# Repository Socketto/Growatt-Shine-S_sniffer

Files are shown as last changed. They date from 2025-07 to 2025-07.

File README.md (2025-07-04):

# Growatt SPH Inverter Communication Sniffer

## Project Overview

This project aims to develop a custom hardware interface and software system for reading and interpreting communication data from a **Growatt SPH series inverter**. The system intercepts the communication between the inverter and the official **ShineWiFi-S dongle**, using signal conversion and a **Raspberry Pi** to capture and decode the **Modbus RTU protocol** used by Growatt.
  
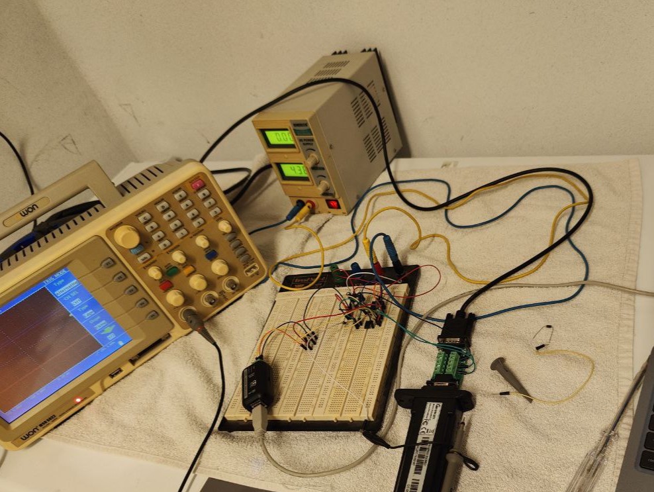
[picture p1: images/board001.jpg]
Board1
 
   
## System Architecture

The solution is composed of the following main stages:

1. **Sniffing the RS-232 Communication**  
   The inverter and ShineWiFi-S dongle communicate over an **RS-232 serial connection**. This project taps into that communication without interfering with the normal operation of either device.

2. **RS-232 to TTL Conversion**  
   Because RS-232 voltage levels are not directly compatible with most microcontrollers or logic analyzers, the tapped signal is first converted to **TTL level signals** using an RS-232 to TTL converter module (MAX232).

3. **TTL to RS-485 Conversion**  
   To ensure signal integrity over longer distances and allow for differential signaling, the TTL signal is then converted to **RS-485** using a TTL to RS-485 transceiver (MAX485).

4. **Data Acquisition via Raspberry Pi**  
   The RS-485 output is connected to a **Raspberry Pi**, which acts as the main controller. The Raspberry Pi receives the data through its serial interface.

5. **Modbus Decoding and Data Interpretation**  
   A **Python script** running on the Raspberry Pi listens to the serial port, decodes the Modbus RTU frames, and extracts relevant data such as:

   - Inverter status
   - Power production
   - Battery charge/discharge
   - Grid voltage and frequency
   - And other available telemetry

## Hardware Components

- Growatt SPH series inverter
- ShineWiFi-S dongle (OEM)
- Breakout DB9
- Raspberry Pi (any model with UART support)
- Optional: Logic level shifters and protective diodes

## Key Advantages

- **Non-intrusive monitoring** of Growatt inverter communication
- **Real-time access** to detailed inverter data
- Enables custom logging, alerting, or integration with home automation platforms (e.g., Home Assistant)

## Disclaimer

This project involves tapping into proprietary communication and working with high voltages indirectly. **Ensure all safety precautions are followed** and use this project at your own risk. This is intended for **educational and personal use only**.

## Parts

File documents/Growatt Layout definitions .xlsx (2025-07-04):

Instruction：Register range for various types of inverter TL-X（MIN Type）：03 register range：0~124,3000~3124；04 register range：3000~3124,3125~3249 TL3-X(MAX、MID、MAC Type)：03 register range：0~124,125~249； 04 register range：0~124,125~249 Storage(MIX Type)：03 register range：0~124,1000~1124；04 register range：0~124,1000~1124 Storage(SPA Type)：03 register range：0~124,1000~1124；04 register range：1000~1124,2000~2124 Storage(SPH Type)：03 register range：0~124,1000~1124；04 register range：0~124,1000~1124
4.2 Input Reg
NO. | Variable Name | Description | Value | Unit | Note | Grott Field name | Grott Offset | Remark | Grott Layout definition
First group
0 | Inverter Status | Inverter run state | 0:waiting, 1:normal, 3:fault |  |  | pvstatus | 158 |  | "pvstatus" : {"value" :158, "length" : 2, "type" : "num"},
1 | Ppv H | Input power (high) |  | 0.1W |  | pvpowerin | 162 |  | "pvpowerin" : {"value" :162, "length" : 4, "type" : "num", "divide" : 10},
2 | Ppv L | Input power (low) |  | 0.1W |  |  | 166
3 | Vpv1 | PV1 voltage |  | 0.1V |  | pv1voltage | 170 |  | "pv1voltage" : {"value" :170, "length" : 2, "type" : "num", "divide" : 10},
4 | PV1Curr | PV1 input current |  | 0.1A |  | pv1current | 174 |  | "pv1current" : {"value" :174, "length" : 2, "type" : "num", "divide" : 10},
5 | Ppv1 H | PV1 input power(high) |  | 0.1W |  | pv1watt | 178 |  | "pv1watt" : {"value" :178, "length" : 4, "type" : "num", "divide" : 10},
6 | Ppv1 L | PV1 input power(low) |  | 0.1W |  |  | 182
7 | Vpv2 | PV2 voltage |  | 0.1V |  | pv2voltage | 186 |  | "pv2voltage" : {"value" :186, "length" : 2, "type" : "num", "divide" : 10},
8 | PV2Curr | PV2 input current |  | 0.1A |  | pv2current | 190 |  | "pv2current" : {"value" :190, "length" : 2, "type" : "num", "divide" : 10},
9 | Ppv2 H | PV2 input power (high) |  | 0.1W |  | pv2watt | 194 |  | "pv2watt" : {"value" :194, "length" : 4, "type" : "num", "divide" : 10},
10 | Ppv2 L | PV2 input power (low) |  | 0.1W |  |  | 198
11 | Vpv3 | PV3 voltage |  | 0.1V |  |  | 202
12 | PV3Curr | PV3 input current |  | 0.1A |  |  | 206
13 | Ppv3 H | PV3 input power (high) |  | 0.1W |  |  | 210
14 | Ppv3 L | PV3 input power (low) |  | 0.1W |  |  | 214
15 | Vpv4 | PV4 voltage |  | 0.1V |  |  | 218
16 | PV4Curr | PV4 input current |  | 0.1A |  |  | 222
17 | Ppv4 H | PV4 input power (high) |  | 0.1W |  |  | 226
18 | Ppv4 L | PV4 input power (low) |  | 0.1W |  |  | 230
19 | Vpv5 | PV5 voltage |  | 0.1V |  |  | 234
20 | PV5Curr | PV5 input current |  | 0.1A |  |  | 238
21 | Ppv5H | PV5 input power(high) |  | 0.1W |  |  | 242
22 | Ppv5 L | PV5 input power(low) |  | 0.1W |  |  | 246
23 | Vpv6 | PV6 voltage |  | 0.1V |  |  | 250
24 | PV6Curr | PV6 input current |  | 0.1A |  |  | 254
25 | Ppv6 H | PV6 input power (high) |  | 0.1W |  |  | 258
26 | Ppv6 L | PV6 input power (low) |  | 0.1W |  |  | 262
27 | Vpv7 | PV7 voltage |  | 0.1V |  |  | 266
28 | PV7Curr | PV7 input current |  | 0.1A |  |  | 270
29 | Ppv7 H | PV7 input power (high) |  | 0.1W |  |  | 274
30 | Ppv7 L | PV7 input power (low) |  | 0.1W |  |  | 278
31 | Vpv8 | PV8 voltage |  | 0.1V |  |  | 282
32 | PV8Curr | PV8 input current |  | 0.1A |  |  | 286
33 | Ppv8 H | PV8 input power (high) |  | 0.1W |  |  | 290
34 | Ppv8 L | PV8 input power (low) |  | 0.1W |  |  | 294
35 | Pac H | Output power (high) |  | 0.1W |  | pvpowerout | 298 |  | "pvpowerout" : {"value" :298, "length" : 4, "type" : "numx", "divide" : 10},
36 | Pac L | Output power (low) |  | 0.1W |  |  | 302
37 | Fac | Grid frequency |  | 0.01Hz |  | pvfrequentie | 306 |  | "pvfrequentie" : {"value" :306, "length" : 2, "type" : "num", "divide" : 100},
38 | Vac1 | Three/single phase grid voltage |  | 0.1V |  | pvgridvoltage | 310 |  | "pvgridvoltage" : {"value" :310, "length" : 2, "type" : "num", "divide" : 10},
39 | Iac1 | Three/single phase grid output current |  | 0.1A |  | pvgridcurrent | 314 |  | "pvgridcurrent" : {"value" :314, "length" : 2, "type" : "num", "divide" : 10},
40 | Pac1 H | Three/single phase grid output watt VA (high) |  | 0.1VA |  | pvgridpower | 318 |  | "pvgridpower" : {"value" :318, "length" : 4, "type" : "num", "divide" : 10},
41 | Pac1 L | Three/single phase grid output watt VA(low) |  | 0.1VA |  |  | 322
42 | Vac2 | Three phase grid voltage |  | 0.1V |  | pvgridvoltage2 | 326 |  | "pvgridvoltage2" : {"value" :326, "length" : 2, "type" : "num", "divide" : 10},
43 | Iac2 | Three phase grid output current |  | 0.1A |  | pvgridcurrent2 | 330 |  | "pvgridcurrent2" : {"value" :330, "length" : 2, "type" : "num", "divide" : 10},
44 | Pac2 H | Three phase grid output power (high) |  | 0.1VA |  | pvgridpower2 | 334 |  | "pvgridpower2" : {"value" :334, "length" : 4, "type" : "num", "divide" : 10},
45 | Pac2 L | Three phase grid output power (low) |  | 0.1VA |  | pvgridvoltage3 | 338
46 | Vac3 | Three phase grid voltage |  | 0.1V |  |  | 342 |  | "pvgridvoltage3" : {"value" :342, "length" : 2, "type" : "num", "divide" : 10},
47 | Iac3 | Three phase grid output current |  | 0.1A |  | pvgridcurrent | 346 |  | "pvgridcurrent3" : {"value" :346, "length" : 2, "type" : "num", "divide" : 10},
48 | Pac3 H | Three phase grid output power (high) |  | 0.1VA |  | pvgridpower | 350 |  | "pvgridpower3" : {"value" :350, "length" : 4, "type" : "num", "divide" : 10},
49 | Pac3 L | Three phase grid output power (low) |  | 0.1VA |  |  | 354
50 | Vac_RS | Three phase grid voltage |  | 0.1V | Line voltage |  | 358
51 | Vac_ST | Three phase grid voltage |  | 0.1V | Line voltage |  | 362
52 | Vac_TR | Three phase grid voltage |  | 0.1V | Line voltage |  | 366
53 | Eactoday H | Today generate energy (high) |  | 0.1kWH |  | eactoday. Pvenergytoday | 370 |  | "eactoday" : {"value" :370, "length" : 4, "type" : "num", "divide" : 10}, "pvenergytoday" : {"value" :370, "length" : 4, "type" : "num", "divide" : 10},
54 | Eac today L | Today generate energy (low) |  | 0.1kWH |  |  | 374
55 | Eac total H | Total generate energy (high) |  | 0.1kWH |  | eactotal | 378 |  | "eactotal" : {"value" :378, "length" : 4, "type" : "num", "divide" : 10},
56 | Eac total L | Total generate energy (low) |  | 0.1kWH |  |  | 382
57 | Time total H | Work time total (high) |  | 0.5s |  | totworktime | 386 |  | "totworktime" : {"value" :386, "length" : 4, "type" : "num", "divide" : 7200},
58 | Time total L | Work time total (low) |  | 0.5s |  |  | 390
59 | Epv1_today H | PV1Energy today(high) |  | 0.1kWh |  | epv1today | 394 |  | "epv1today" : {"value" :394, "length" : 4, "type" : "num", "divide" : 10},
60 | Epv1_today L | PV1Energy today (low) |  | 0.1kWh |  |  | 398
61 | Epv1_total H | PV1Energy total(high) |  | 0.1kWh |  | epv1total | 402 |  | "epv1total" : {"value" :402, "length" : 4, "type" : "num", "divide" : 10},
62 | Epv1_total L | PV1Energy total (low) |  | 0.1kWh |  |  | 406
63 | Epv2_today H | PV2Energy today(high) |  | 0.1kWh |  | epv2today | 410 |  | "epv2today" : {"value" :410, "length" : 4, "type" : "num", "divide" : 10},
64 | Epv2_today L | PV2Energy today (low) |  | 0.1kWh |  |  | 414
65 | Epv2_total H | PV2Energy total(high) |  | 0.1kWh |  | epv2total | 418 |  | "epv2total" : {"value" :418, "length" : 4, "type" : "num", "divide" : 10},
66 | Epv2_total L | PV2Energy total (low) |  | 0.1kWh |  |  | 422
67 | Epv3_today H | PV3 Energy today(high) |  | 0.1kWh |  |  | 426
68 | Epv3_today L | PV3 Energy today (low) |  | 0.1kWh |  |  | 430
69 | Epv3_total H | PV3 Energy total(high) |  | 0.1kWh |  |  | 434
70 | Epv3_total L | PV3 Energy total (low) |  | 0.1kWh |  |  | 438
71 | Epv4_today H | PV4Energy today(high) |  | 0.1kWh |  |  | 442
72 | Epv4_today L | PV4Energy today (low) |  | 0.1kWh |  |  | 446
73 | Epv4_total H | PV4Energy total(high) |  | 0.1kWh |  |  | 450
74 | Epv4_total L | PV4Energy total (low) |  | 0.1kWh |  |  | 454
75 | Epv5_today H | PV5Energy today(high) |  | 0.1kWh |  |  | 458
76 | Epv5_today L | PV5Energy today (low) |  | 0.1kWh |  |  | 462
77 | Epv5_total H | PV5Energy total(high) |  | 0.1kWh |  |  | 466
78 | Epv5_total L | PV5Energy total (low) |  | 0.1kWh |  |  | 470
79 | Epv6_today H | PV6Energy today(high) |  | 0.1kWh |  |  | 474
80 | Epv6_today L | PV6Energy today (low) |  | 0.1kWh |  |  | 478
81 | Epv6_total H | PV6Energy total(high) |  | 0.1kWh |  |  | 482
82 | Epv6_total L | PV6Energy total (low) |  | 0.1kWh |  |  | 486
83 | Epv7_today H | PV7Energy today(high) |  | 0.1kWh |  |  | 490
84 | Epv7_today L | PV7Energy today (low) |  | 0.1kWh |  |  | 494
85 | Epv7_total H | PV7 Energy total(high) |  | 0.1kWh |  |  | 498
86 | Epv7_total L | PV7Energy total (low) |  | 0.1kWh |  |  | 502
87 | Epv8_today H | PV8Energy today(high) |  | 0.1kWh |  |  | 506
88 | Epv8_today L | PV8Energy today (low) |  | 0.1kWh |  |  | 510
89 | Epv8_total H | PV8Energy total(high) |  | 0.1kWh |  |  | 514
90 | Epv8_total L | PV8Energy total (low) |  | 0.1kWh |  |  | 518
91 | Epv_total H | PV Energy total(high) |  | 0.1kWh |  | epvtotal | 522 |  | "epvtotal" : {"value" :522, "length" : 4, "type" : "num", "divide" : 10},
92 | Epv_total L | PV Energy total (low) |  | 0.1kWh |  |  | 526
93 | Temp1 | Inverter temperature |  | 0.1C |  | pvtemperature | 530 |  | "pvtemperature" : {"value" :530, "length" : 2, "type" : "num", "divide" : 10},
94 | Temp2 | The inside IPM in inverter Temperature |  | 0.1C |  | pvipmtemperature" | 534 |  | "pvipmtemperature" : {"value" :534, "length" : 2, "type" : "num", "divide" : 10},
95 | Temp3 | Boost temperature |  | 0.1C |  | pvboosttemp | 538 |  | "pvboosttemp" : {"value" :538, "length" : 2, "type" : "num", "divide" : 10},
96 | Temp4 |  |  |  | reserved |  | 542
97 | uwBatVolt_DSP | BatVolt_DSP |  | 0.1V | BatVolt(DSP) | bat_dsp | 546 | Only shown with includeall = True (.ini) or gincludeall ="True" (docker) | "bat_dsp" : {"value" :546, "length" : 2, "type" : "num", "divide" : 10},
98 | P Bus Voltage | P Bus inside Voltage |  | 0.1V |  | pbusvolt | 550 | Only shown with includeall = True (.ini) or gincludeall ="True" (docker) | "pbusvolt" : {"value" :550, "length" : 2, "type" : "num", "divide" : 10,"incl" : "no"},
99 | N Bus Voltage | N Bus inside Voltage |  | 0.1V |  | #nbusvolt | 554 | Only shown with includeall = True (.ini) or gincludeall ="True" (docker) | "#nbusvolt" : {"value" :554, "length" : 2, "type" : "num", "divide" : 10,"incl" : "no"},
100 | IPF | Inverter output PF now | 0-20000 |  |  | #ipf | 558 | Only shown with includeall = True (.ini) or gincludeall ="True" (docker) | "#ipf" : {"value" :558, "length" : 2, "type" : "num", "divide" : 10,"incl" : "no"},
101 | RealOPPercent | Real Output power Percent |  | 1% |  | #realoppercent | 562 | Only shown with includeall = True (.ini) or gincludeall ="True" (docker) | "#realoppercent" : {"value" :562, "length" : 2, "type" : "num", "divide" : 100,"incl" : "no"},
102 | OPFullwatt H | Output Maxpower Limited high |  |  |  | #opfullwat | 566 | Only shown with includeall = True (.ini) or gincludeall ="True" (docker) | "#opfullwatt" : {"value" :566, "length" : 4, "type" : "num", "divide" : 10,"incl" : "no"},
103 | OPFullwatt L | Output Maxpower Limited low |  | 0.1W |  |  | 570
104 | DeratingMode | DeratingMode | 0:no derate; 1:PV; 2:*; 3:Vac; 4:Fac; 5:Tboost; 6:Tinv; 7:Control; 8:*; 9:*OverBack ByTime; |  |  | #deratingmode | 574 | Only shown with includeall = True (.ini) or gincludeall ="True" (docker) | "#deratingmode" : {"value" :574, "length" : 2, "type" : "num", "divide" : 1,"incl" : "no"},
105 | Fault code | Inverter fault code | &*1 |  | MAX |  | 578
106 | Fault Bitcode H | Inverter fault code high | &*8 |  | MAX |  | 582
107 | Fault Bitcode L | Inverter fault code low |  |  |  |  | 586
108 | RemoteCtrlEn | / | 0.Load First 1.BatFirst 2.Grid | / | StoragePow er (SPA) |  | 590
109 | RemoteCtrlPow er | / |  | / | StoragePow er (SPA) |  | 594
110 | Warning bit H | Warning bit H | &*8 |  |  |  | 598
111 | Warning bit L | Warning bit L |  |  |  |  | 602
112 | bINVWarnCode | bINVWarnCode |  |  | MAX |  | 606 |  | "eacharge_today" : {"value" :606, "length" : 4, "type" : "num", "divide" : 10},
 | EACharge_Today _H | ACCharge energy today |  | 0.1kwh | Storage Power | acharge_today
113 | real Power Percent | real Power Percent | 0-100 | % | MAX |  | 610
 | EACharge_Today _L | ACCharge energy today |  | 0.1kwh | Storage Power
114 | inv start delay time | inv start delay time |  |  | MAX |  | 614 |  | "eacharge_total" : {"value" :614, "length" : 4, "type" : "num", "divide" : 10},
 | EACharge_Total _H | ACCharge energy total |  | 0.1kwh | Storage Power | eacharge_total
115 | bINVAllFaultCod e | bINVAllFaultCode |  |  | MAX |  | 618
 | EACharge_Total _L | ACCharge energy total |  | 0.1kwh | Storage Power |  | 158
116 | AC charge Power_H | Grid power to local load |  | 0.1kwh | Storage Power |  | 622
117 | AC charge Power_L | Grid power to local load |  | 0.1kwh | Storage Power |  | 626
118 | Priority | 0:Load First 1:Battery First 2:Grid First |  |  | Storage Power |  | 630
119 | Battery Type | 0：Lead-acid 1：Lithium battery |  |  | Storage Power | batterytype | 634 |  | "batterytype" : {"value" :634, "length" : 2, "type" : "num", "divide" : 1},
120 | AutoProofreadC MD | Aging mode 自动校准命令 |  |  | Storage Power |  | 638
… | reserved |  |  |  | reserved
124 | reserved |  |  |  | reserved |  | 654
Second group
125 | PID PV1+ Voltage | PID PV1PE Volt | 0~1000V | 0.1V
126 | PID PV1+ Current | PID PV1PE Curr | -10~10mA | 0.1mA
127 | PID PV2+ Voltage | PID PV2PE Volt | 0~1000V | 0.1V
128 | PID PV2+ Current | PID PV2PE Curr | -10~10mA | 0.1mA
129 | PID PV3+ Voltage | PID PV3PE Volt | 0~1000V | 0.1V
130 | PID PV3+ Current | PID PV3PE Curr | -10~10mA | 0.1mA
131 | PID PV4+ Voltage | PID PV4PE Volt | 0~1000V | 0.1V
132 | PID PV4+ Current | PID PV4PE Curr | -10~10mA | 0.1mA
133 | PID PV5+ Voltage | PID PV5PE Volt | 0~1000V | 0.1V
134 | PID PV5+ Current | PID PV5PE Curr | -10~10mA | 0.1mA
135 | PID PV6+ Voltage | PID PV6PE Volt | 0~1000V | 0.1V
136 | PID PV6+ Current | PID PV6PE Curr | -10~10mA | 0.1mA
137 | PID PV7+ Voltage | PID PV7PE Volt | 0~1000V | 0.1V
138 | PID PV7+ Current | PID PV7PE Curr | -10~10mA | 0.1mA
139 | PID PV8+ Voltage | PID PV8PE Volt | 0~1000V | 0.1V
140 | PID PV8+ Current | PID PV8PE Curr | -10~10mA | 0.1mA
141 | PID Status | Bit0~7:PID Working Status 1:Wait Status 2:Normal Status 3:Fault Status Bit8~15:Reversed | 0~3
142 | V _String1 | PV String1 voltage |  | 0.1V
143 | Curr _String1 | PV String1 current | -15~15A | 0.1A
144 | V _String2 | PV String2 voltage |  | 0.1V
145 | Curr _String2 | PV String2 current | -15~15A | 0.1A
146 | V _String3 | PV String3 voltage |  | 0.1V
147 | Curr _String3 | PV String3 current | -15~15A | 0.1A
148 | V _String4 | PV String4 voltage |  | 0.1V
149 | Curr _String4 | PV String4 current | -15~15A | 0.1A
150 | V _String5 | PV String5 voltage |  | 0.1V
151 | Curr _String5 | PV String5 current | -15~15A | 0.1A
152 | V _String6 | PV String6 voltage |  | 0.1V
153 | Curr _String6 | PV String6 current | -15~15A | 0.1A
154 | V _String7 | PV String7 voltage |  | 0.1V
155 | Curr _String7 | PV String7 current | -15~15A | 0.1A
156 | V _String8 | PV String8 voltage |  | 0.1V
157 | Curr _String8 | PV String8 current | -15A~15A | 0.1A
158 | V _String9 | PV String9 voltage |  | 0.1V
159 | Curr _String9 | PV String9 current | -15A~15A | 0.1A
160 | V _String10 | PV String10 voltage |  | 0.1V
161 | Curr _String10 | PV String10 current | -15~15A | 0.1A
162 | V _String11 | PV String11 voltage |  | 0.1V
163 | Curr _String11 | PV String11 current | -15~15A | 0.1A
164 | V _String12 | PV String12 voltage |  | 0.1V
165 | Curr _String12 | PV String12 current | -15~15A | 0.1A
166 | V _String13 | PV String13 voltage |  | 0.1V
167 | Curr _String13 | PV String13 current | -15A~15A | 0.1A
168 | V _String14 | PV String14 voltage |  | 0.1V
169 | Curr _String14 | PV String14 current | -15~15A | 0.1A
170 | V _String15 | PV String15 voltage |  | 0.1V
171 | Curr _String15 | PV String15 current | -15~15A | 0.1A
172 | V _String16 | PV String16 voltage |  | 0.1V
173 | Curr _String16 | PV String16 current | -15~15A | 0.1A
174 | StrUnmatch | Bit0~15: String1~16 unmatch |  |  | suggestive
175 | StrCurrentUnblan ce | Bit0~15: String1~16 current unblance |  |  | suggestive
176 | StrDisconnect | Bit0~15: String1~16 disconnect |  |  | suggestive
177 | PIDFaultCode | Bit0:Output over voltage Bit1: ISO fault Bit2: BUS voltage abnormal Bit3~15:reserved
178 | String Prompt | String Prompt Bit0:String Unmatch Bit1:StrDisconnect Bit2:StrCurrentUnblance Bit3~15:reserved
179 | PV Warning Value | PV Warning Value
180 | DSP075 Warning Value | DSP075 Warning Value
181 | DSP075 Fault Value | DSP075 Fault Value
182 | DSP067 Debug Data1 | DSP067 Debug Data1
183 | DSP067 Debug Data2 | DSP067 Debug Data2
184 | DSP067 Debug Data3 | DSP067 Debug Data3
185 | DSP067 Debug Data4 | DSP067 Debug Data4
186 | DSP067 Debug Data5 | DSP067 Debug Data5
187 | DSP067 Debug Data6 | DSP067 Debug Data6
188 | DSP067 Debug Data7 | DSP067 Debug Data7
189 | DSP067 Debug Data8 | DSP067 Debug Data8
190 | DSP075 Debug Data1 | DSP075 Debug Data1
191 | DSP075 Debug Data2 | DSP075 Debug Data2
192 | DSP075 Debug Data3 | DSP075 Debug Data3
193 | DSP075 Debug Data4 | DSP075 Debug Data4
194 | DSP075 Debug Data55 | DSP075 Debug Data5
195 | DSP075 Debug Data6 | DSP075 Debug Data6
196 | DSP075 Debug Data7 | DSP075 Debug Data7
197 | DSP075 Debug Data8 | DSP075 Debug Data8
198 | bUSBAgingTestOk Flag | USBAgingTestOkFlag | 0-1
199 | bFlashEraseAging OkFlag | FlashEraseAgingOkFlag | 0-1
200 | PVISO | PVISOValue |  | KΩ
201 | R_DCI | R DCI Curr |  | 0.1mA
202 | S_DCI | S DCI Curr |  | 0.1mA
203 | T_DCI | T DCI Curr |  | 0.1mA
204 | PID_Bus | PIDBusVolt |  | 0.1V
205 | GFCI | GFCI Curr |  | mA
206 | SVG/APF Status+SVGAPFEq ualRatio | SVG/APF Status+SVGAPFEqualRatio | High 8 bit： SVGAPFEqua lRatio Low 8 bit： SVG/APF Status 0:None 1:SVG Run 2:APF Run 3:SVG/APF Run
207 | CT_I _R | R phase load side current for SVG |  | 0.1A
208 | CT_I _S | S phase load side current for SVG |  | 0.1A
209 | CT_I _T | T phase load side current for SVG |  | 0.1A
210 | CT_Q _R H | R phase load side output reactive power for SVG(High) |  | 0.1Var
211 | CT_Q _R L | R phase load side output reactive power for SVG(low) |  | 0.1Var
212 | CT_Q _S H | S phase load side output reactive power for SVG(High) |  | 0.1Var
213 | CT_Q _S L | S phase load side output reactive power for SVG(low) |  | 0.1Var
214 | CT_Q _T H | T phase load side output reactive power for SVG(High) |  | 0.1Var
215 | CT_Q _T L | T phase load side output reactive power for SVG(low) |  | 0.1Var
216 | CT HAR_I_R | R phase load side harmonic |  | 0.1A
217 | CT HAR_I_S | S phase load side harmonic |  | 0.1A
218 | CT HAR_I_T | T phase load side harmonic |  | 0.1A
219 | COMP_Q _R H | R phase compensate reactive power for SVG(High) |  | 0.1Var
220 | COMP_Q _R L | R phase compensate reactive power for SVG(low) |  | 0.1Var
221 | COMP_Q _S H | S phase compensate reactive power for SVG(High) |  | 0.1Var
222 | COMP_Q _S L | S phase compensate reactive power for SVG(low) |  | 0.1Var
223 | COMP_Q _T H | T phase compensate reactive power for SVG(High) |  | 0.1Var
224 | COMP_Q _T L | T phase compensate reactive power |  | 0.1Var
 |  | for SVG(low)
225 | COMP HAR_I_R | R phase compensate harmonic for SVG |  | 0.1A
226 | COMP HAR_I_S | S phase compensate harmonic for SVG |  | 0.1A
227 | COMP HAR_I_T | T phase compensate harmonic for SVG |  | 0.1A
228 | bRS232AgingTest OkFlag | RS232AgingTestOkFlag | 0-1
229 | bFanFaultBit | Bit0: Fan 1 fault bit Bit1: Fan 2 fault bit Bit2: Fan 3 fault bit Bit3: Fan 4 fault bit Bit4-7: Reserved
230 | Sac H | Output apparent power H |  | 0.1W
231 | Sac L | Output apparent power L |  | 0.1W
232 | ReActPowerH | Real Output Reactive Power H | Int32 | 0.1W
233 | ReActPowerL | Real Output Reactive Power L
234 | ReActPowerMaxH | Nominal Output Reactive Power H |  | 0.1var
235 | ReActPowerMaxL | Nominal Output Reactive Power L
236 | ReActPower_Total H | Reactive power generation |  | 0.1kwh
237 | ReActPower_Total L | Reactive power generation
… | 238~249 |  |  |  | reserved
Ninth group for Storage power
1000 | uwSysWorkMode | System work mode | 0x00:waiting module 0x01: Self-test mode, optional 0x02 : Reserved 0x03：SysFault module 0x04: Flash module 0x05 ： PVBATOnline module, 0x06 ： BatOnline module 0x07 ： PVOfflineMod e module, 0x08 ： BatOfflineMo de module, |  | Theworkingmode displayed by the monitoring to the customer is： 0x00: waiting module 0x01: Self-test mode, 0x03:fault module 0x04:flash module 0x05|0x06|0x07|0 x08:normal module |  | 666 |  | "uwsysworkmode" : {"value" :666, "length" : 2, "type" : "num", "divide" : 1}, | #REF!
1001 | Systemfault word0 | System fault word0 |  |  | Please refer to thefault description of Hybrid | systemfaultword0 | 670 |  | "systemfaultword0" : {"value" :670, "length" : 2, "type" : "num", "divide" : 1},
1002 | Systemfault word1 | System fault word1 |  |  |  | systemfaultword1 | 674 |  | "systemfaultword1" : {"value" :674, "length" : 2, "type" : "num", "divide" : 1},
1003 | Systemfault word2 | System fault word2 |  |  |  | systemfaultword2 | 678 |  | "systemfaultword2" : {"value" :678, "length" : 2, "type" : "num", "divide" : 1},
1004 | Systemfault word3 | System fault word3 |  |  |  | systemfaultword3 | 682 |  | "systemfaultword3" : {"value" :682, "length" : 2, "type" : "num", "divide" : 1},
1005 | Systemfault word4 | System fault word4 |  |  |  | systemfaultword4 | 686 |  | "systemfaultword4" : {"value" :686, "length" : 2, "type" : "num", "divide" : 1},
1006 | Systemfault word5 | System fault word5 |  |  |  | systemfaultword5 | 690 |  | "systemfaultword5" : {"value" :690, "length" : 2, "type" : "num", "divide" : 1},
1007 | Systemfault word6 | System fault word6 |  |  |  | systemfaultword6 | 694 |  | "systemfaultword6" : {"value" :694, "length" : 2, "type" : "num", "divide" : 1},
1008 | Systemfault word7 | System fault word7 |  |  |  | systemfaultword7 | 698 |  | "systemfaultword7" : {"value" :698, "length" : 2, "type" : "num", "divide" : 1},
1009 | Pdischarge1 H | Discharge power(high) |  | 0.1W |  | pdischarge1 | 702 |  | "pdischarge1" : {"value" :702, "length" : 4, "type" : "num", "divide" : 10},
1010 | Pdischarge1 L | Discharge power (low) |  | 0.1W |  |  | 706
1011 | Pcharge1 H | Charge power(high) |  | 0.1W |  | p1charge1 | 710 |  | "p1charge1" : {"value" :710, "length" : 4, "type" : "num", "divide" : 10},
1012 | Pcharge1 L | Charge power (low) |  | 0.1W |  |  | 714
1013 | Vbat | Battery voltage |  | 0.1V |  | vbat | 718 |  | "vbat" : {"value" :718, "length" : 2, "type" : "num", "divide" : 10},
1014 | SOC | State of charge Capacity | 0-100 | 1% | lith/leadacid | SOC | 722 |  | "SOC" : {"value" :722, "length" : 2, "type" : "num", "divide" : 100},
1015 | Pactouser R H | AC power to user H |  | 0.1w |  | pactouserr | 726 |  | "pactouserr" : {"value" :726, "length" : 4, "type" : "num", "divide" : 10},
1016 | Pactouser R L | AC power to user L |  | 0.1w |  |  | 730
1017 | Pactouser S H | Pactouser S |  | 0.1w |  | #pactousers | 734 | Only shown with includeall = True (.ini) or gincludeall ="True" (docker) | "#pactousers" : {"value" :734, "length" : 4, "type" : "num", "divide" : 10,"incl" : "no"},
1018 | Pactouser S L | Pactouser S |  | 0.1w |  |  | 738
1019 | Pactouser T H | Pactouser T |  | 0.1w |  | #pactousert | 742 | Only shown with includeall = True (.ini) or gincludeall ="True" (docker) | "#pactousert" : {"value" :742, "length" : 4, "type" : "num", "divide" : 10,"incl" : "no"},
1020 | Pactouser T L | Pactouser T |  | 0.1w |  |  | 746
1021 | PactouserTotal H | AC power to user total H |  | 0.1w |  | pactousertot | 750 |  | "pactousertot" : {"value" :750, "length" : 4, "type" : "num", "divide" : 10},
1022 | PactouserTotal L | AC power to user total L |  | 0.1w |  |  | 754
1023 | Pac to grid R H | AC power to grid H |  | 0.1w | Ac output | pactogridr | 758 |  | "pactogridr" : {"value" :758, "length" : 4, "type" : "num", "divide" : 10},
1024 | Pac to grid R L | AC power to grid L |  | 0.1w |  |  | 762
1025 | Pactogrid S H |  |  | 0.1w |  | #pactogrids | 766 | Only shown with includeall = True (.ini) or gincludeall ="True" (docker) | "#pactogrids" : {"value" :766, "length" : 4, "type" : "num", "divide" : 10,"incl" : "no"},
1026 | Pactogrid S L |  |  | 0.1w |  |  | 770
1027 | Pactogrid T H |  |  | 0.1w |  | #pactogridt | 774 | Only shown with includeall = True (.ini) or gincludeall ="True" (docker) | "#pactogridt" : {"value" :774, "length" : 4, "type" : "num", "divide" : 10,"incl" : "no"},
1028 | Pactogrid T L |  |  | 0.1w |  |  | 778
1029 | Pactogrid total H | AC power to grid total H |  | 0.1w |  | pactogridto | 782 |  | "pactogridtot" : {"value" :782, "length" : 4, "type" : "num", "divide" : 10},
1030 | Pactogrid total L | AC power to grid total L |  | 0.1w |  |  | 786
1031 | PLocalLoad R H | INV power to local load H |  | 0.1w |  | plocaloadr | 790 |  | "plocaloadr" : {"value" :790, "length" : 4, "type" : "num", "divide" : 10},
1032 | PLocalLoad R L | INV power to local load L |  | 0.1w |  |  | 794
1033 | PLocalLoad S H |  |  | 0.1w |  | #plocaloads | 798 | Only shown with includeall = True (.ini) or gincludeall ="True" (docker) | "#plocaloads" : {"value" :798, "length" : 4, "type" : "num", "divide" : 10,"incl" : "no"},
1034 | PLocalLoad S L |  |  | 0.1w |  |  | 802
1035 | PLocalLoadT H |  |  | 0.1w |  | #plocaloadt | 806 | Only shown with includeall = True (.ini) or gincludeall ="True" (docker) | "#plocaloadt" : {"value" :806, "length" : 4, "type" : "num", "divide" : 10,"incl" : "no"},
1036 | PLocalLoadT L |  |  | 0.1w |  |  | 810
1037 | PLocalLoad total H | INV power to local load total H |  | 0.1w |  | plocaloadto | 814 |  | "plocaloadtot" : {"value" :814, "length" : 4, "type" : "num", "divide" : 10},
1038 | PLocalLoad total L | INV power to local load total L |  | 0.1w |  |  | 818
1039 | IPM Temperature | REC Temperature |  | 0.1℃ | No use | #ipm | 822 | Only shown with includeall = True (.ini) or gincludeall ="True" (docker) | "#ipm" : {"value" :822, "length" : 2, "type" : "num", "divide" : 10,"incl" : "no"},
1040 | Battery Temperature | Battery Temperature |  | 0.1℃ | Lead acid/lithium battery temp | #battemp | 826 | Only shown with includeall = True (.ini) or gincludeall ="True" (docker) | "#battemp" : {"value" :826, "length" : 2, "type" : "num", "divide" : 10,"incl" : "no"},
1041 | SP DSP Status | SP state |  |  | CHG/DisCHG | spdspstatus | 830 |  | "spdspstatus" : {"value" :830, "length" : 2, "type" : "num", "divide" : 10},
1042 | SP Bus Volt | SP BUS2 Volt |  | 0.1V |  | spbusvolt | 834 |  | "spbusvolt" : {"value" :834, "length" : 2, "type" : "num", "divide" : 10},
1043 |  |  |  |  |  |  | 838
发电量数据
1044 | Etouser_today H | Energy to user today high |  | 0.1kWh |  | etouser_tod | 842 |  | "etouser_tod" : {"value" :842, "length" : 4, "type" : "num", "divide" : 10},
1045 | Etouser_today L | Energy to user today low |  | 0.1kWh |  |  | 846
1046 | Etouser_total H | Energy to user total high |  | 0.1kWh |  | etouser_tot | 850 |  | "etouser_tot" : {"value" :850, "length" : 4, "type" : "num", "divide" : 10},
1047 | Etouser_ total L | Energy to user total high |  | 0.1kWh |  |  | 854
1048 | Etogrid_today H | Energy to grid today high |  | 0.1kWh |  | etogrid_tod | 858 |  | "etogrid_tod" : {"value" :858, "length" : 4, "type" : "num", "divide" : 10},
1049 | Etogrid _today L | Energy to grid today low |  | 0.1kWh |  |  | 862
1050 | Etogrid _total H | Energy to grid total high |  | 0.1kWh |  | etogrid_tot | 866 |  | "etogrid_tot" : {"value" :866, "length" : 4, "type" : "num", "divide" : 10},
1051 | Etogrid _ total L | Energy to grid total high |  | 0.1kWh |  |  | 870
1052 | Edischarge1_toda y H | Discharge energy1 today |  | 0.1kWh |  | edischarge1_tod | 874 |  | "edischarge1_tod" : {"value" :874, "length" : 4, "type" : "num", "divide" : 10},
1053 | Edischarge1_toda y L | Discharge energy1 today |  | 0.1kWh |  |  | 878
1054 | Edischarge1_total H | Total discharge energy1 (high) |  | 0.1kWh |  | edischarge1_tot | 882 |  | "edischarge1_tot" : {"value" :882, "length" : 4, "type" : "num", "divide" : 10},
1055 | Edischarge1_total L | Total discharge energy1 (low) |  | 0.1kWh |  |  | 886
1056 | Echarge1_today H | Charge1 energy today |  | 0.1kWh |  | eharge1_tod | 890 |  | "eharge1_tod" : {"value" :890, "length" : 4, "type" : "num", "divide" : 10},
1057 | Echarge1_today L | Charge1 energy today |  | 0.1kWh |  |  | 894
1058 | Echarge1_total H | Charge1 energy total |  | 0.1kWh |  | eharge1_to | 898 |  | "eharge1_tot" : {"value" :898, "length" : 4, "type" : "num", "divide" : 10},
1059 | Echarge1_total L | Charge1 energy total |  | 0.1kWh |  |  | 902
1060 | ELocalLoad_Today H | Local load energy today |  | 0.1kWh |  | elocalload_tod | 906 |  | "elocalload_tod" : {"value" :906, "length" : 4, "type" : "num", "divide" : 10},
1061 | ELocalLoad_Today L | Local load energy today |  | 0.1kWh |  |  | 910
1062 | ELocalLoad_Total H | Local load energy total |  | 0.1kWh |  | elocalload_tot | 914 |  | "elocalload_tot" : {"value" :914, "length" : 4, "type" : "num", "divide" : 10}
1063 | ELocalLoad_Total L | Local load energy total |  | 0.1kWh |  |  | 918
1064 | dwExportLimitAp parentPower | ExportLimitApparentPower H |  | 0.1kWh | ApparentPower |  | 922
1065 | dwExportLimitAp parentPower | ExportLimitApparentPower L |  | 0.1kWh | ApparentPower |  | 926
1066 | / | / | / | / | reserved |  | 930
1067 | EPS Fac | UPSfrequency | 5000/6000 | 0.01Hz |  |  | 934
1068 | EPS Vac1 | UPS phase R output voltage | 2300 | 0.1V |  |  | 938
1069 | EPS Iac1 | UPS phase R output current |  | 0.1A |  |  | 942
1070 | EPS Pac1 H | UPS phase R output power (H) |  | 0.1VA |  |  | 946
1071 | EPS Pac1 L | UPS phase R output power (L) |  | 0.1VA |  |  | 950
1072 | EPS Vac2 | UPS phase S output voltage |  | 0.1V |  |  | 954
1073 | EPS Iac2 | UPS phase S output current |  | 0.1A | No use |  | 958
1074 | EPS Pac2 H | UPS phase S output power (H) |  | 0.1VA |  |  | 962
1075 | EPS Pac2 L | UPS phase S output power (L) |  | 0.1VA |  |  | 966
1076 | EPS Vac3 | UPS phase T output voltage |  | 0.1V |  |  | 970
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

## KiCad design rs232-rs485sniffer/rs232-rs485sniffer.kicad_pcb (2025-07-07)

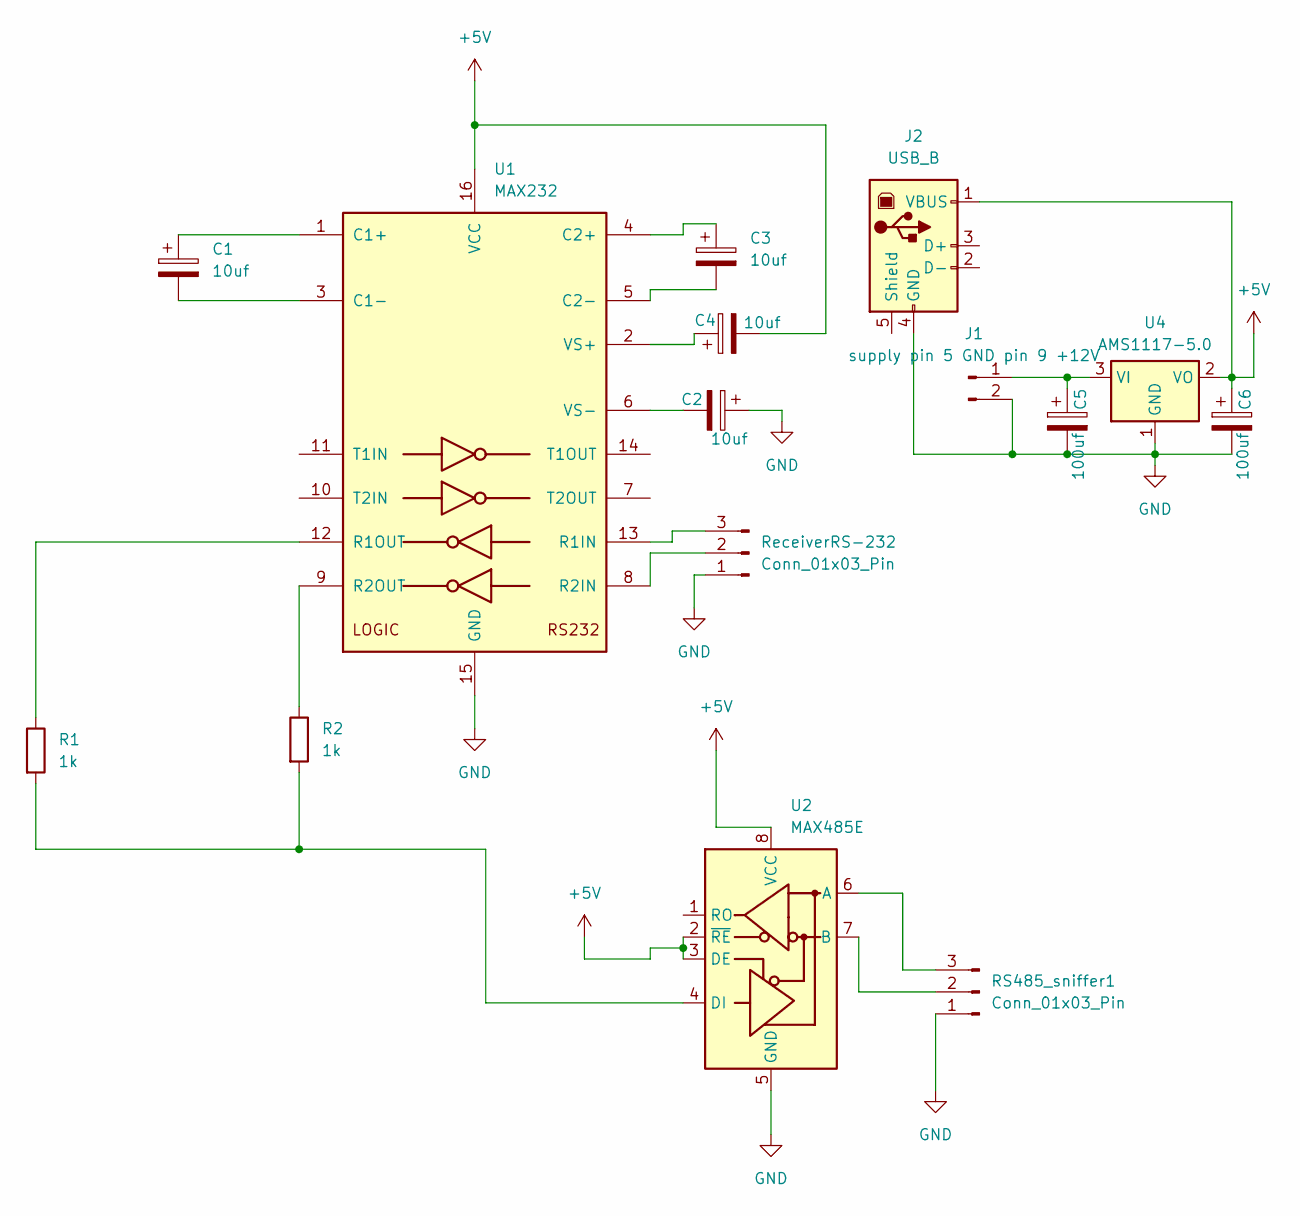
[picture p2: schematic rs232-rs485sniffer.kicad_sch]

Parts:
C1, C2, C3, C4: 10uf; CP_Radial_D8.0mm_P3.80mm
C5, C6: 100uf; CP_Radial_D8.0mm_P3.80mm
J1: supply pin 5 GND pin 9 +12V; TerminalBlock_Phoenix_MKDS-1,5-2_1x02_P5.00mm_Horizontal
J2: USB_B; USB_B_Lumberg_2411_02_Horizontal
R1, R2: 1k; L_1206_3216Metric_Pad1.22x1.90mm_HandSolder
RS485_sniffer1: Conn_01x03_Pin; TerminalBlock_Phoenix_MKDS-1,5-3-5.08_1x03_P5.08mm_Horizont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
ReceiverRS-232: Conn_01x03_Pin; TerminalBlock_Phoenix_MKDS-1,5-3-5.08_1x03_P5.08mm_Horizont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
U1: MAX232; DIP-16_W7.62mm_Socket_LongPads
U2: MAX485E; SOIC-8_3.9x4.9mm_P1.27mm
U4: AMS1117-5.0; SOT-223-3_TabPin2

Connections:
+5V: C4.2, C6.1, J2.1 (VBUS), U1.16 (VCC), U2.2 (~RE), U2.3 (DE), U2.8 (VCC), U4.2 (VO)
GND: C2.1, C5.2, C6.2, J1.2, J2.4 (GND), RS485_sniffer1.1, ReceiverRS-232.1, U1.15 (GND), U2.5 (GND), U4.1 (GND)
unnamed: C5.1, J1.1, U4.3 (VI)
unnamed: RS485_sniffer1.2, U2.7 (B)
unnamed: RS485_sniffer1.3, U2.6 (A)
unnamed: ReceiverRS-232.2, U1.8 (R2IN)
unnamed: ReceiverRS-232.3, U1.13 (R1IN)
unnamed: C1.1, U1.1 (C1+)
unnamed: C1.2, U1.3 (C1-)
unnamed: C3.1, U1.4 (C2+)
unnamed: C3.2, U1.5 (C2-)
unnamed: R1.1, U1.12 (R1OUT)
unnamed: R2.1, U1.9 (R2OUT)
unnamed: C4.1, U1.2 (VS+)
unnamed: C2.2, U1.6 (VS-)
unnamed: R1.2, R2.2, U2.4 (DI)

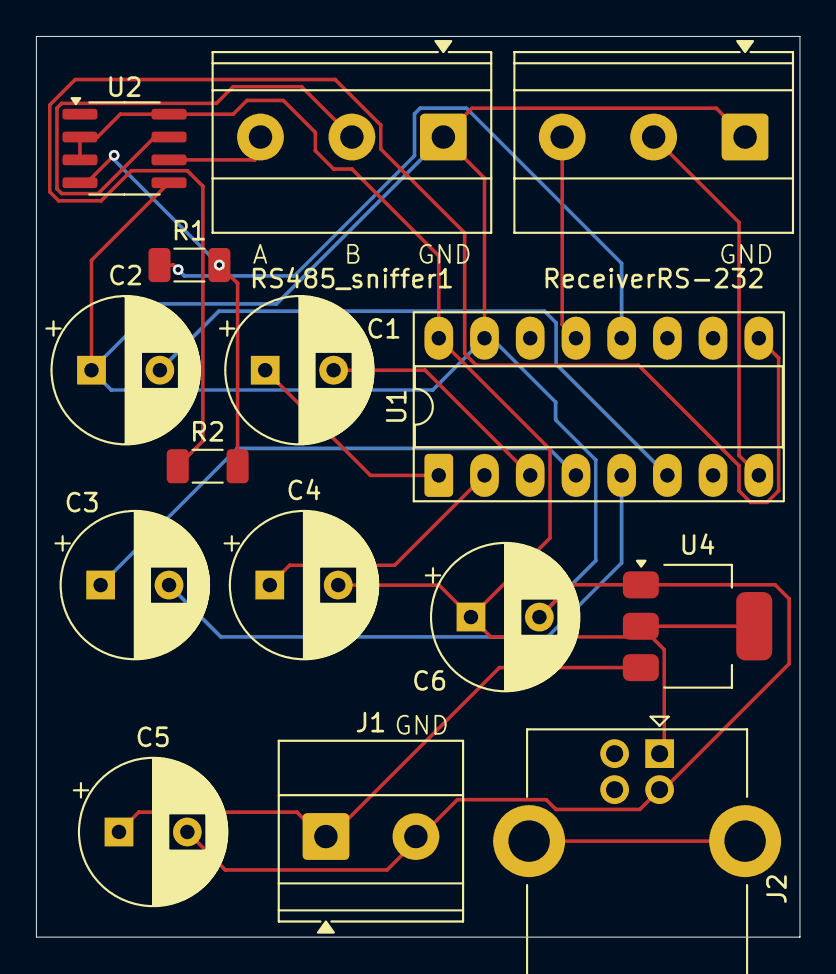
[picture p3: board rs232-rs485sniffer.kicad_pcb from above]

Board: 2 copper layers, 42.4 x 50.0 mm, 15 parts (0 on the bottom side), 16 nets.

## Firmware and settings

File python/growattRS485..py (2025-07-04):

import serial.tools.list_ports
import serial
import time

def GetSerial():
    for p in serial.tools.list_ports.comports():
        if p.vid == 1027 and p.pid == 24577:
            print(f"RS485 device: {p.device}")
            return p.device

TableModbusHR = dict()
TableModbusIR = dict()


def crc16(data: bytes) -> int:
    crc = 0xFFFF
    for pos in data:
        crc ^= pos
        for _ in range(8):
            if crc & 1:
                crc >>= 1
                crc ^= 0xA001
            else:
                crc >>= 1
    return crc


class BrutalModbusParser:
    def __init__(self, modbus_id):
        self.modbus_id = modbus_id
        self.buffer = bytearray()
        self.last_request_info = None  # (start_addr, quantity)

    def feed(self, data: bytes):
        self.buffer.extend(data)
        max_search_len = 256

        i = 0
        while i < len(self.buffer) - 1:
            if self.buffer[i] == self.modbus_id and (self.buffer[i + 1] == 0x03 or self.buffer[i + 1] == 0x04):
                self.request_type =  self.buffer[i + 1]
                max_msg_len = min(max_search_len, len(self.buffer) - i)
                found_valid = False
                for msg_len in range(5, max_msg_len + 1):
                    msg = self.buffer[i : i + msg_len]
                    if len(msg) < 5:
                        continue
                    crc_calc = crc16(msg[:-2])
                    crc_msg = msg[-2] + (msg[-1] << 8)
                    if crc_calc == crc_msg:
                        # Messaggio valido
                        if msg_len == 8:
                            self._process_request(msg)
                        else:
                            self._process_response(msg)
                        del self.buffer[: i + msg_len]
                        i = -1  # riparte da zero al prossimo ciclo
                        found_valid = True
                        break
                if not found_valid:
                    i += 1
            else:
                i += 1

        if len(self.buffer) > 1024:
            self.buffer = self.buffer[-512:]

    def _process_request(self, msg: bytes):
        # Richiesta: ID + CMD + StartAddr (2) + Quantity (2) + CRC (2)
        start_addr = (msg[2] << 8) + msg[3]
        quantity = (msg[4] << 8) + msg[5]
        self.last_request_info = (start_addr, quantity)
        print(
            f"\n[RICHIESTA] Lettura da registro {start_addr} per {quantity} registri."
        )

    def _process_response(self, msg: bytes):
        global TableModbus
        # Risposta: ID + CMD + ByteCount + Dati(n) + CRC
        if len(msg) < 5:
            return
        byte_count = msg[2]
        data = msg[3 : 3 + byte_count]
        if len(data) != byte_count:
            print("[!] Byte count non corrispondente ai dati.")
            return

        registers = []
        for i in range(0, byte_count, 2):
            reg = (data[i] << 8) + data[i + 1]
            registers.append(reg)

        if self.last_request_info:
            start_addr, _ = self.last_request_info
        else:
            start_addr = 0  # se mancante, usa offset base

        print(f"\n[RISPOSTA] Registri letti da {start_addr}:")
        for idx, val in enumerate(registers):
            print(f"  Registro type:{self.request_type} -> {start_addr + idx}: {val}")
            if self.request_type == 0x03:
                TableModbusHR[start_addr + idx] = val
            if self.request_type == 0x04:
                TableModbusIR[start_addr + idx] = val


def main():
    ser = serial.Serial(port=GetSerial(), baudrate=9600, timeout=0.1)
    parser = BrutalModbusParser(modbus_id=0x01)

    try:
        while True:
            data = ser.read(64)
            if data:
                parser.feed(data)
            else:
                time.sleep(0.01)
    except KeyboardInterrupt:
        ser.close()
        print("Seriale chiusa.")
        print(dict(sorted(TableModbusHR.items())))
        print(dict(sorted(TableModbusIR.items())))


if __name__ == "__main__":
    main()

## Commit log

2025-07-02 [FIRST] First draft of board to convert signal RS-232 in RS-485 signals
    [rs232-rs485sniffer.kicad_pcb, rs232-rs485sniffer.kicad_sch]
2025-07-03 [ADD] Add board and add management with unique rs-485 transceiver
    [rs232-rs485sniffer.kicad_pcb, rs232-rs485sniffer.kicad_sch]
2025-07-04 [UPD] Update schematic and add docs
    [Growatt Layout definitions .xlsx, rs232-rs485sniffer.kicad_sch]
2025-07-04 [FIX] Add complete board v1 with gerber file
    [rs232-rs485sniffer.kicad_pcb]
2025-07-07 [ADD] Add 2 resistor to moderate signal of TTL
    [rs232-rs485sniffer.kicad_pcb, rs232-rs485sniffer.kicad_sch]
